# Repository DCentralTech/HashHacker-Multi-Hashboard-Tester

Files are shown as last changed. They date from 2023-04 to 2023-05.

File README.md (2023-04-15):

# HashHacker-Multi-Hashboard-Tester
HashHacker Multi-Hashboard Tester from D-Central, the ultimate open-source tool for repairing and testing your ASIC miners. We plan features such as advanced and intuitive interface, the HashHacker Multi-Hashboard Tester is designed to help you quickly and easily diagnose and fix any issues with your mining hardware.

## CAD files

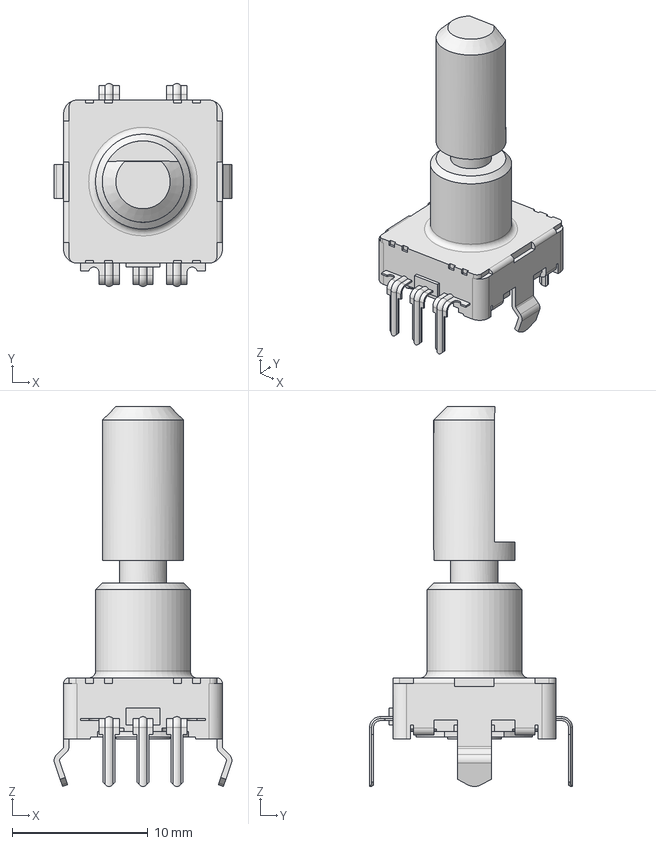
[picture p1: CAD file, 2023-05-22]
eec.models/ALPS_-_EC11E15244B2.step
13.1 x 14.9 x 28.0 mm

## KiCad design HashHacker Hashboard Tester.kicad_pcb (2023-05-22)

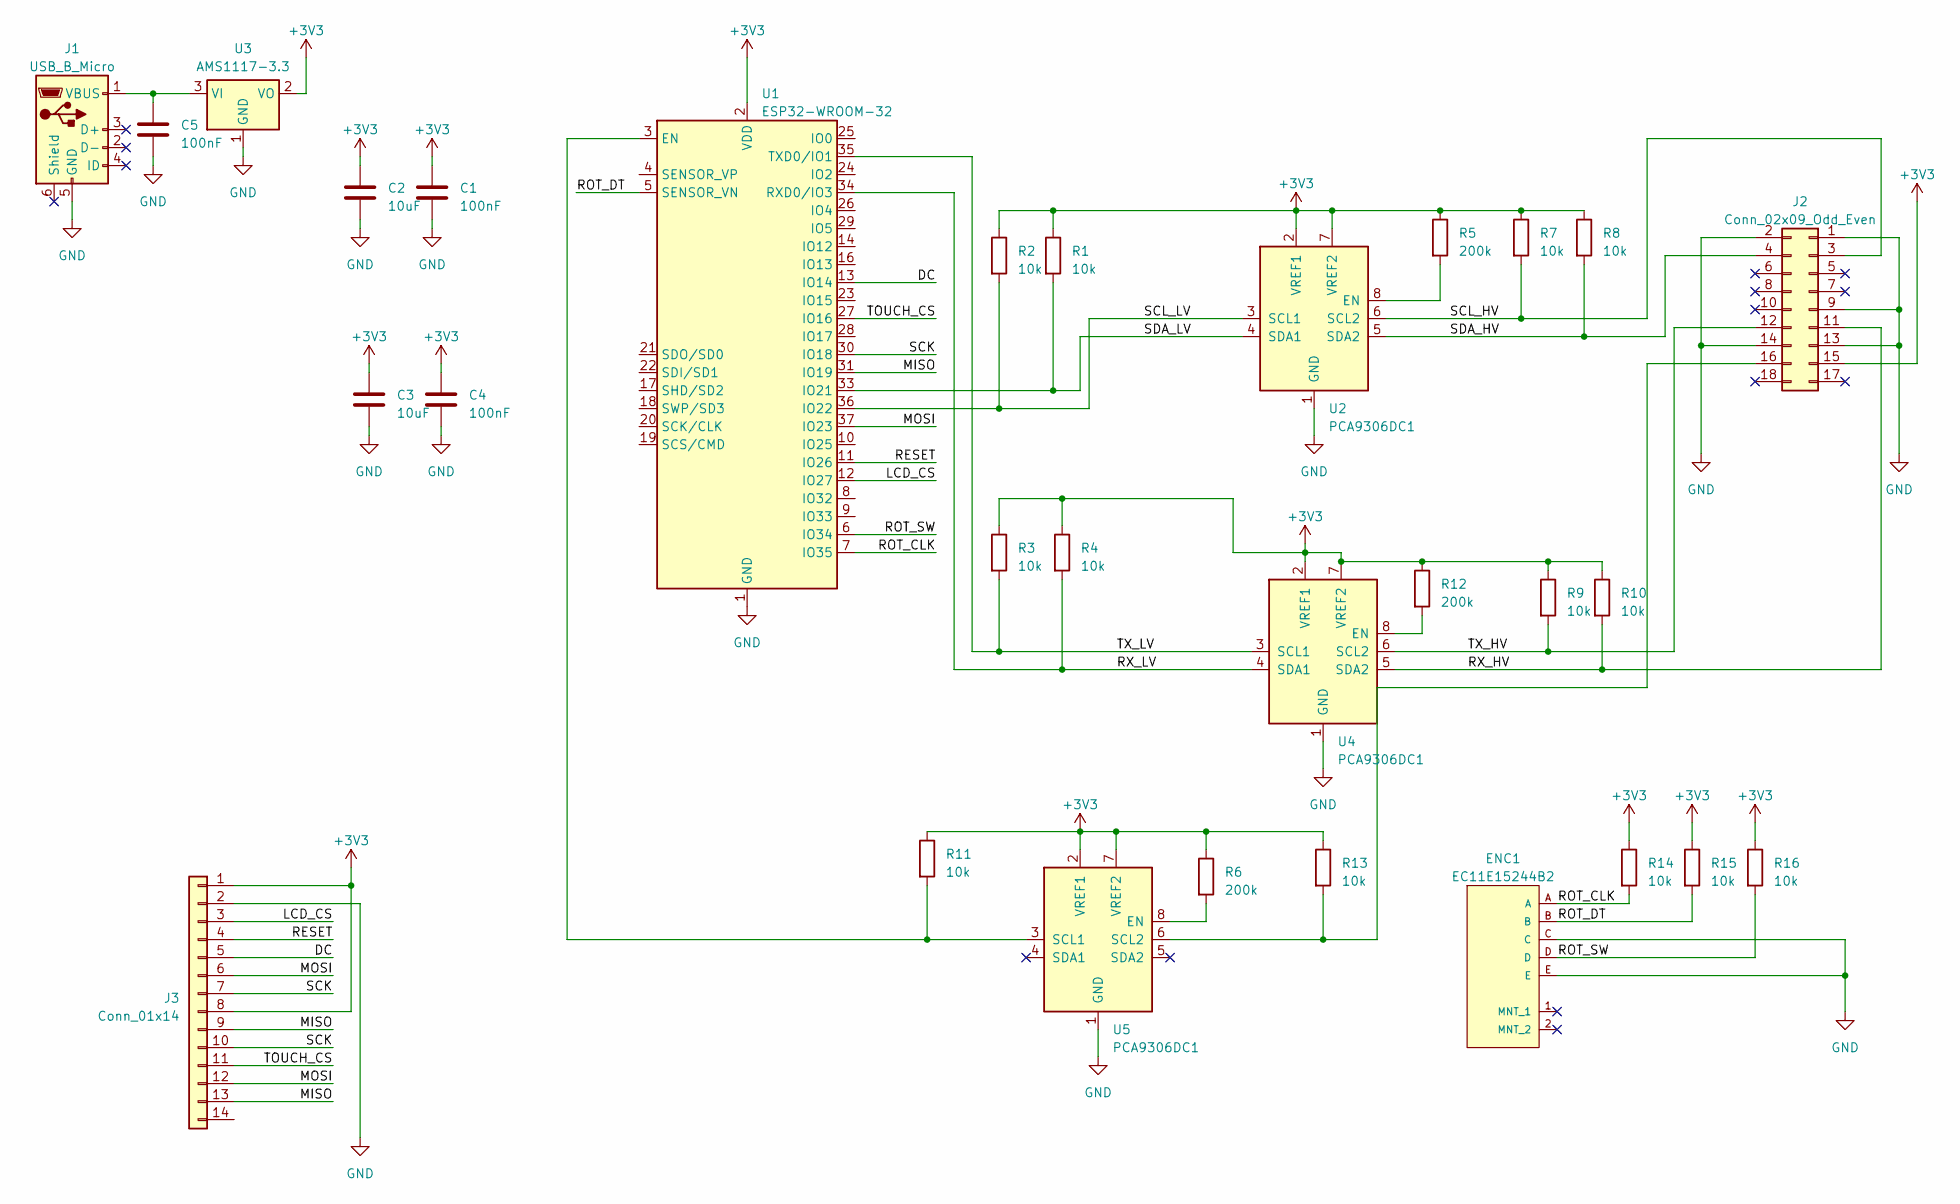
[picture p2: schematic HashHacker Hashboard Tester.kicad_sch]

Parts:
C1, C4, C5: 100nF; C_0402_1005Metric; Manufacturer P/N CL05B104KB54PNC; LCSC P/N C307331
C2, C3: 10uF; C_0402_1005Metric; Manufacturer P/N CL05A106MQ5NUNC; LCSC P/N C15525
ENC1: EC11E15244B2; ALPS-EC11E15244B2-0; Ratings 10mA 5V DC; mouser part number 688-EC11E15244B2
J1: USB_B_Micro; USB_Micro-AB_Molex_47590-0001; Manufacturer P/N 475900001; LCSC P/N C136001
J2: Conn_02x09_Odd_Even; PinSocket_2x09_P2.00mm_Vertical
J3: Conn_01x14; PinSocket_1x14_P2.54mm_Vertical; Manufacturer P/N PM254-1-14-Z-8.5; LCSC P/N C2897377
R1, R2, R3, R4, R7, R8, R9, R10, R11, R13, R14, R15, R16: 10k; R_0402_1005Metric; Manufacturer P/N 0402WGF100KTCE; LCSC P/N C25086
R5, R6, R12: 200k; R_0402_1005Metric; Manufacturer P/N 0402WGF2003TCE; LCSC P/N C25764
U1: ESP32-WROOM-32; Manufacturer P/N ESP32-WROOM-32-N4; LCSC P/N C82899
U2, U4, U5: PCA9306DC1; VSSOP-8_2.3x2mm_P0.5mm; Manufacturer P/N PCA9306DC1; LCSC P/N C129510
U3: AMS1117-3.3; SOT-223-3_TabPin2; Manufacturer P/N AMS1117-3.3; LCSC P/N C6186

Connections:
+3V3: C1.1, C2.1, C3.1, C4.1, J2.15, J3.1, J3.8, R1.1, R2.1, R3.1, R4.1, R5.1, R6.1, R7.1, R8.1, R9.1, R10.1, R11.1, R12.1, R13.1, R14.1, R15.1, R16.1, U1.2 (VDD), U2.2 (VREF1), U2.7 (VREF2), U3.2 (VO), U4.2 (VREF1), U4.7 (VREF2), U5.2 (VREF1), U5.7 (VREF2)
/DC: J3.5, U1.13 (IO14)
/LCD_CS: J3.3, U1.12 (IO27)
/MISO: J3.9, J3.13, U1.31 (IO19)
/MOSI: J3.6, J3.12, U1.37 (IO23)
/RESET: J3.4, U1.11 (IO26)
/ROT_CLK: ENC1.A, R14.2, U1.7 (IO35)
/ROT_DT: ENC1.B, R15.2, U1.5 (SENSOR_VN)
/ROT_SW: ENC1.D, R16.2, U1.6 (IO34)
/RX_HV: J2.11, R10.2, U4.5 (SDA2)
/RX_LV: R4.2, U1.34 (RXD0/IO3), U4.4 (SDA1)
/SCK: J3.7, J3.10, U1.30 (IO18)
/SCL_HV: J2.3, R7.2, U2.6 (SCL2)
/SCL_LV: R2.2, U1.36 (IO22), U2.3 (SCL1)
/SDA_HV: J2.4, R8.2, U2.5 (SDA2)
/SDA_LV: R1.2, U1.33 (IO21), U2.4 (SDA1)
/TOUCH_CS: J3.11, U1.27 (IO16)
/TX_HV: J2.12, R9.2, U4.6 (SCL2)
/TX_LV: R3.2, U1.35 (TXD0/IO1), U4.3 (SCL1)
GND: C1.2, C2.2, C3.2, C4.2, C5.2, ENC1.C, ENC1.E, J1.5 (GND), J2.1, J2.2, J2.9, J2.13, J2.14, J3.2, U1.1 (GND), U1.15 (GND), U1.38 (GND), U1.39 (GND), U2.1 (GND), U3.1 (GND), U4.1 (GND), U5.1 (GND)
unnamed: C5.1, J1.1 (VBUS), U3.3 (VI)
unnamed: J2.16, R13.2, U5.6 (SCL2)
unnamed: R11.2, U1.3 (EN), U5.3 (SCL1)
unnamed: R5.2, U2.8 (EN)
unnamed: R12.2, U4.8 (EN)
unnamed: R6.2, U5.8 (EN)

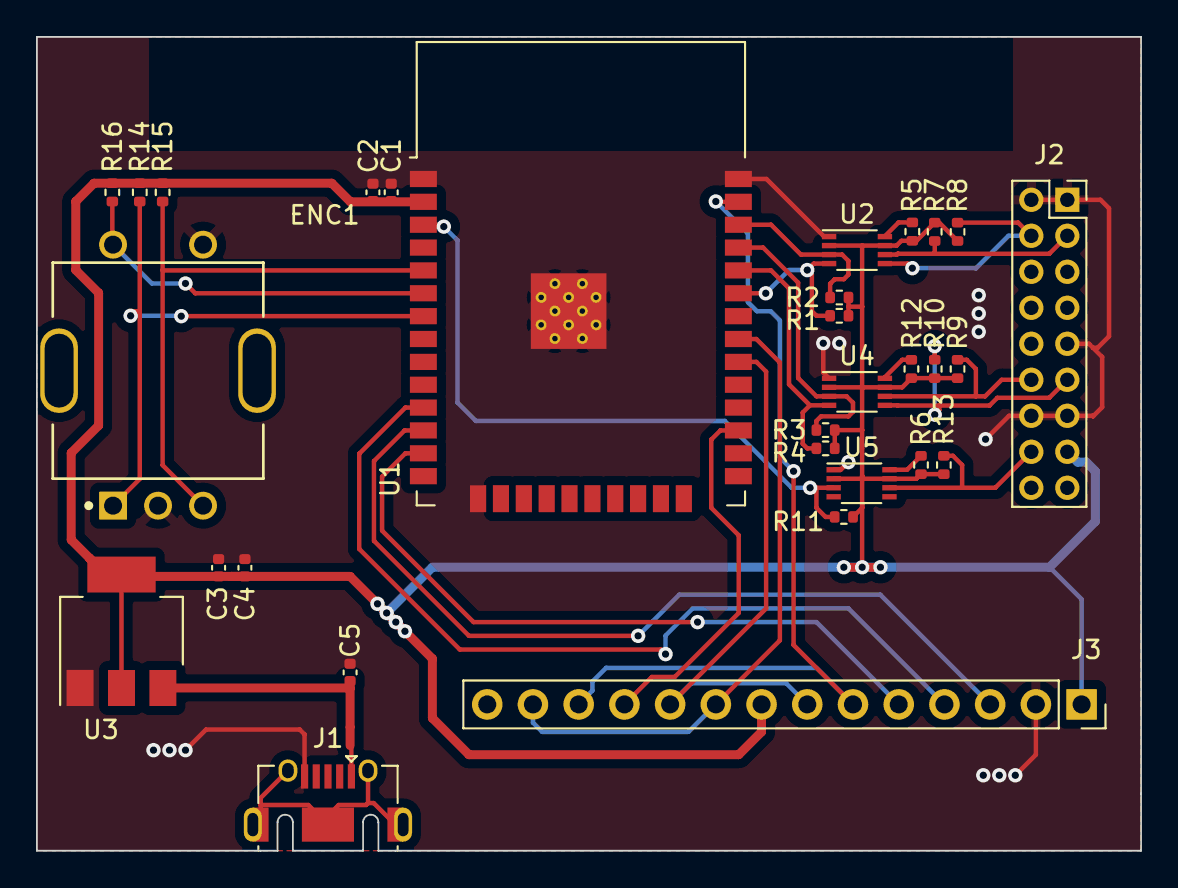
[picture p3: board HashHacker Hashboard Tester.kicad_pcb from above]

Board: 2 copper layers, 61.3 x 45.2 mm, 30 parts (0 on the bottom side), 26 nets.

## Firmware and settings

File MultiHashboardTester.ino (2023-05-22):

#include <Wire.h>
#include <WiFi.h>
#include <ESPAsyncWebServer.h>
#include <TFT_eSPI.h>
#include <SPI.h>

// Replace with your network credentials
const char* ssid = "your_SSID";
const char* password = "your_PASSWORD";

// Initialize TFT display
TFT_eSPI tft = TFT_eSPI();

// Create an instance of the server
AsyncWebServer server(80);

// Define the I2C pins
#define SDA_PIN 21
#define SCL_PIN 22

// Define the selector knob pin
#define SELECTOR_PIN 36

// Define hash board models
enum HashboardModel {
  ANTMINER_L3_PLUS,
  ANTMINER_S9,
  ANTMINER_T15,
  ANTMINER_S15,
  ANTMINER_T17,
  ANTMINER_S17,
  ANTMINER_T17_PLUS,
  ANTMINER_S17_PLUS,
  ANTMINER_T19,
  ANTMINER_S19,
  NUM_MODELS
};

// Current selected model
HashboardModel currentModel = ANTMINER_L3_PLUS;

void setup() {
  // Initialize serial communication
  Serial.begin(115200);

  // Initialize I2C
  Wire.begin(SDA_PIN, SCL_PIN);

  // Initialize TFT display
  tft.init();
  tft.setRotation(1);
  tft.fillScreen(TFT_BLACK);
  tft.setTextColor(TFT_WHITE);
  tft.setTextSize(2);

  // Initialize selector knob
  pinMode(SELECTOR_PIN, INPUT);

  // Connect to Wi-Fi
  WiFi.begin(ssid, password);
  while (WiFi.status() != WL_CONNECTED) {
    delay(1000);
    Serial.println("Connecting to Wi-Fi...");
  }
  Serial.println("Connected to Wi-Fi");

  // Configure server routes
  server.on("/", HTTP_GET, [](AsyncWebServerRequest *request) {
    request->send(200, "text/html", "Welcome to the Multi-hashboard Tester!");
  });

  // Start server
  server.begin();
}

void loop() {
  // Read selector knob value
  int selectorValue = analogRead(SELECTOR_PIN);

  // Determine the selected model based on the selector value
  HashboardModel selectedModel = static_cast<HashboardModel>(map(selectorValue, 0, 4095, 0, NUM_MODELS));

  // If the selected model has changed, update the display and start the test
  if (selectedModel != currentModel) {
    currentModel = selectedModel;
    updateDisplay();
    startTest();
  }

}

void updateDisplay() {
  tft.fillScreen(TFT_BLACK);
  tft.setCursor(0, 0);

  switch (currentModel) {
    case ANTMINER_L3_PLUS:
      tft.print("Antminer L3+");
      break;
    case ANTMINER_S9:
      tft.print("Antminer S9");
      break;
  }
}

void startTest() {
  if (currentModel == ANTMINER_L3_PLUS) {
    test_antminer_l3_plus();
  } else if (currentModel == ANTMINER_S9) {
    test_antminer_s9();
  }
}

void test_antminer_l3_plus() {
}

void test_antminer_s9() {
}

void send_write_command(uint8_t address, uint8_t register, uint8_t data) {
  Wire.beginTransmission(address);
  Wire.write(register);
  Wire.write(data);
  Wire.endTransmission();
}

uint8_t read_data(uint8_t address, uint8_t register) {
  Wire.beginTransmission(address);
  Wire.write(register);
  Wire.endTransmission(false);

  Wire.requestFrom(address, 1);
  if (Wire.available()) {
    return Wire.read();
  } else {
    return 0;
  }
}
